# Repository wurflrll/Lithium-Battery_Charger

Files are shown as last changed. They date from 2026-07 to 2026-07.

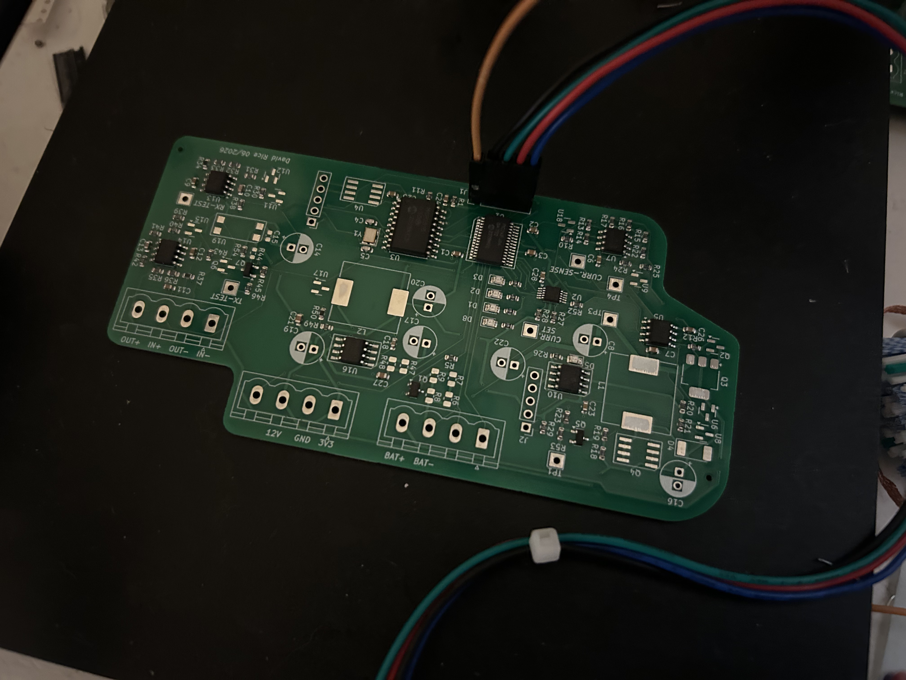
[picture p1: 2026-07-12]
images/oscilloscope/board_image_programmer.jpg

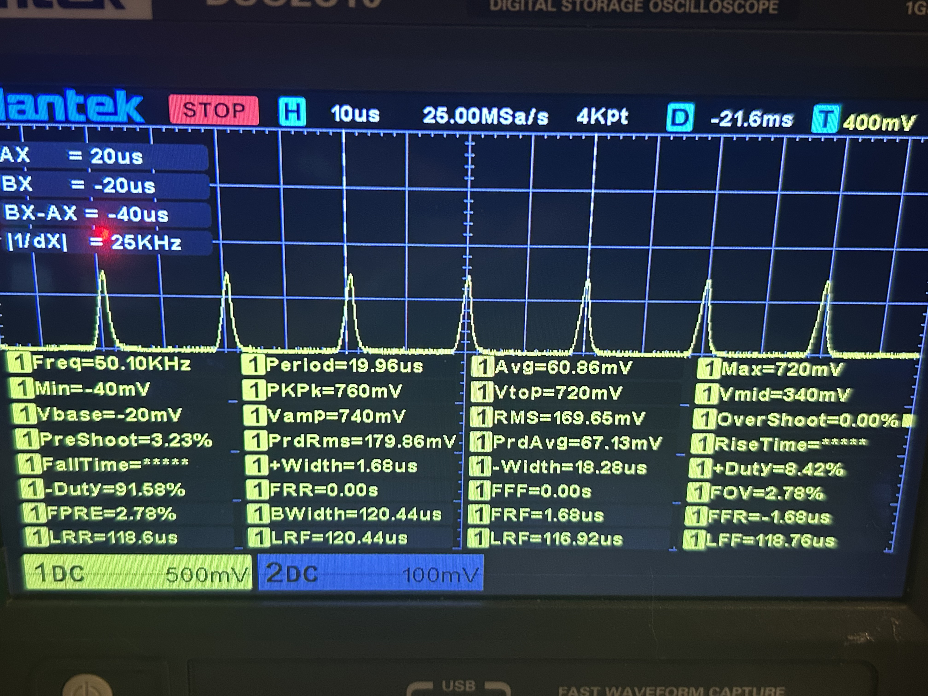
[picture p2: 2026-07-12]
images/oscilloscope/feedback_noise.jpg

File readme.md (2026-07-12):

# (Cascaded) Lithium-Ion Battery Charger 

The goals is a modular design for charging a lithium ion battery.  The board has two parts, the actual charging circuitry and the communication peripherals.

The communication peripherals includes an electrically isolated UART interface over a pulse transformer, an I2C interface to talk to the board's DAC module, and some general purpose inputs and outputs. 

Power Supply: 12V

V1 had a few issues, one was a layout error with the PIC microcontroller (I created the symbols itself in KiCad).  The other issue, much more interesting, is an issue with stability in the constant current controller.

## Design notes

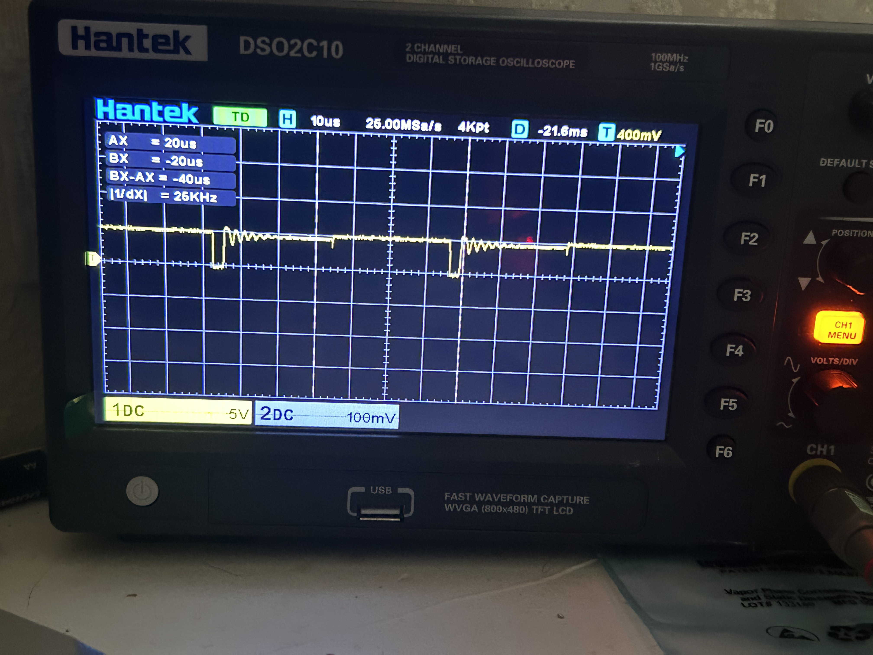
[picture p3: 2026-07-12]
images/oscilloscope/switching_inductive.jpg

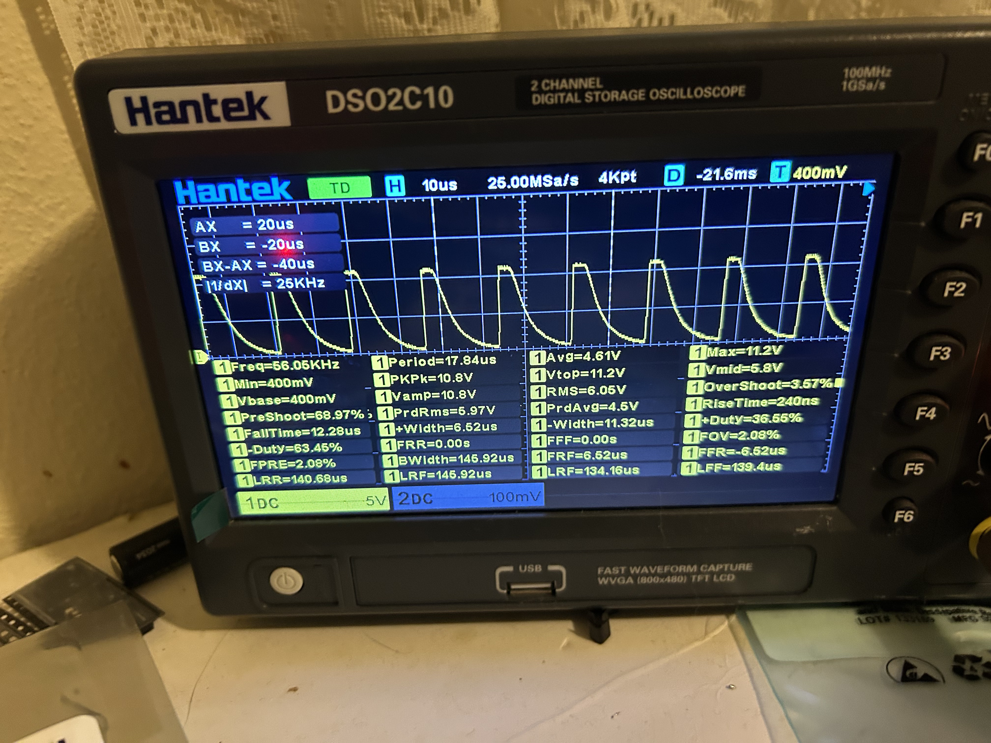
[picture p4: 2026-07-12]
images/oscilloscope/different_load_instability.jpg

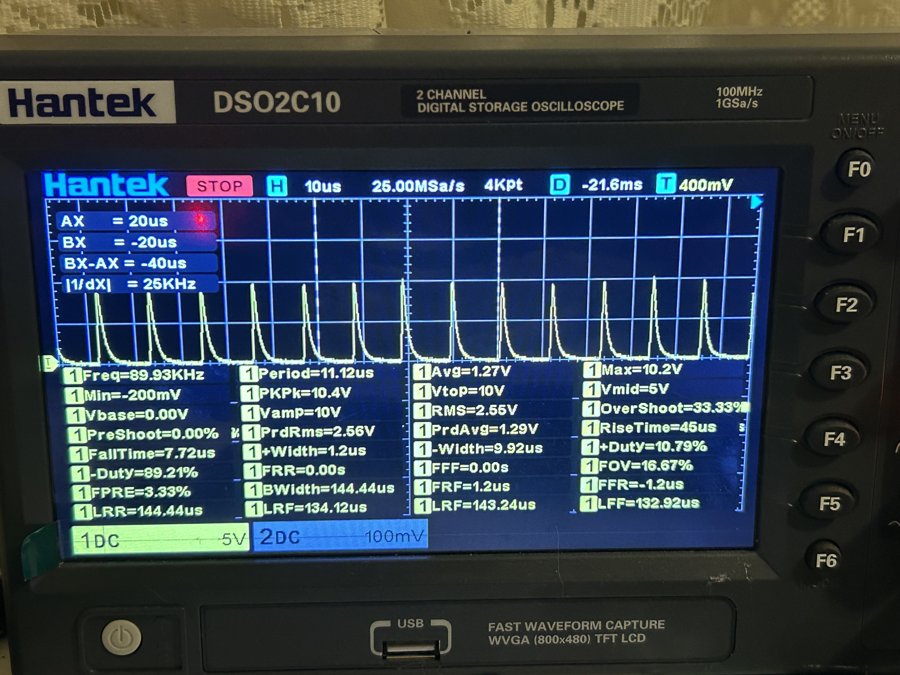
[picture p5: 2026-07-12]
images/oscilloscope/instability.jpg

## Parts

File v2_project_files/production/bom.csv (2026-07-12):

Designator | Footprint | Quantity | Value | LCSC Part #
C1, C11, C12, C2, C23, C24, C25, C26, C28, C6, C9 | 603 | 11 | 1uF | C29936
C10 | 603 | 1 | 22nF | C21122
C13 | 603 | 1 | 2.2nF | C107082
C14, C16, C17, C19, C20, C22, C8 | CP_Radial_D6.3mm_P2.50mm | 7 | 100uF
C18 | 603 | 1 | 1nF | C100040
C21, C27, C3, C7 | 603 | 4 | 10uF | C96446
C4, C5 | 603 | 2 | 30pF | C113797
D1, D2, D3, D5, D8 | 805 | 5 | LED | C19171391
D4 | D_MELF | 1 | SD560B
J1, J2, J4 | PinHeader_1x05_P2.54mm_Vertical | 3 | Conn_01x05_Pin
J3, J5, J6 | PhoenixContact_MSTBVA_2,5_4-G-5,08_1x04_P5.08mm_Vertical | 3 | Conn_01x04_Socket
L1, L2 | L_Sunlord_MWSA1205S-R36 | 2 | 220uH
Q1 | SOT-23 | 1 | AO3400A | C20917
Q2, Q6 | SOT-23 | 2 | Q_NPN_BEC | C81464
Q3 | SOT-223-3_TabPin2 | 1 | NSS60600MZ4 | C235754
Q4 | AOSP21313C | 1 | AOSP21313C
Q5, Q7 | SOT-23 | 2 | 2N7002 | C916396
R1, R11, R12, R13, R21, R27, R28, R29, R40, R41, R42 | 603 | 11 | 4.7K | C99782
R10, R23, R38, R43, R45, R46, R5, R52, R53 | 603 | 9 | 1K | C110776
R14, R15, R16, R17, R20, R22, R24, R25, R30, R32, R33, R35, R36 | 603 | 13 | 10K | C95204
R18, R19, R31, R54 | 603 | 4 | 100R | C122970
R2, R26, R3, R4, R51 | 603 | 5 | 133R | C5126161
R34, R37 | 603 | 2 | 2K | C844924
R39 | 603 | 1 | 510R | C113299
R47 | 805 | 1 | 0.511R
R49 | 603 | 1 | 5.6K | C2907046
R50 | 603 | 1 | 3.3K | C844928
R6, R7, R8, R9 | 805 | 4 | SHUNT?
TP1, TP2, TP3, TP4, TP5, TP8, TP9 | TestPoint_THTPad_2.5x2.5mm_Drill1.2mm | 7 | TestPoint
U1 | PIC24FJ64GA702 | 1 | ~ | C641965
U10 | PIC12F1501 | 1 | ~ | C76411
U11, U12, U15, U17, U18, U6, U8, U9 | ZLLS500TA | 8 | ~ | C154850
U13, U14, U5, U7 | SOIC-8_3.9x4.9mm_P1.27mm | 4 | NCS20072D | C89845
U16 | AZ34063U | 1 | ~ | C99659
U2 | MSOP-10_3x3mm_P0.5mm | 1 | MCP4728
U3 | SOIC-18W_7.5x11.6mm_P1.27mm | 1 | MCP2515-xSO | C153782
U4 | SN65HVD3082EDR | 1 | ~
Y1 | Crystal_SMD_Abracon_ABM8AIG-4Pin_3.2x2.5mm | 1 | Crystal_GND24 | C1986628

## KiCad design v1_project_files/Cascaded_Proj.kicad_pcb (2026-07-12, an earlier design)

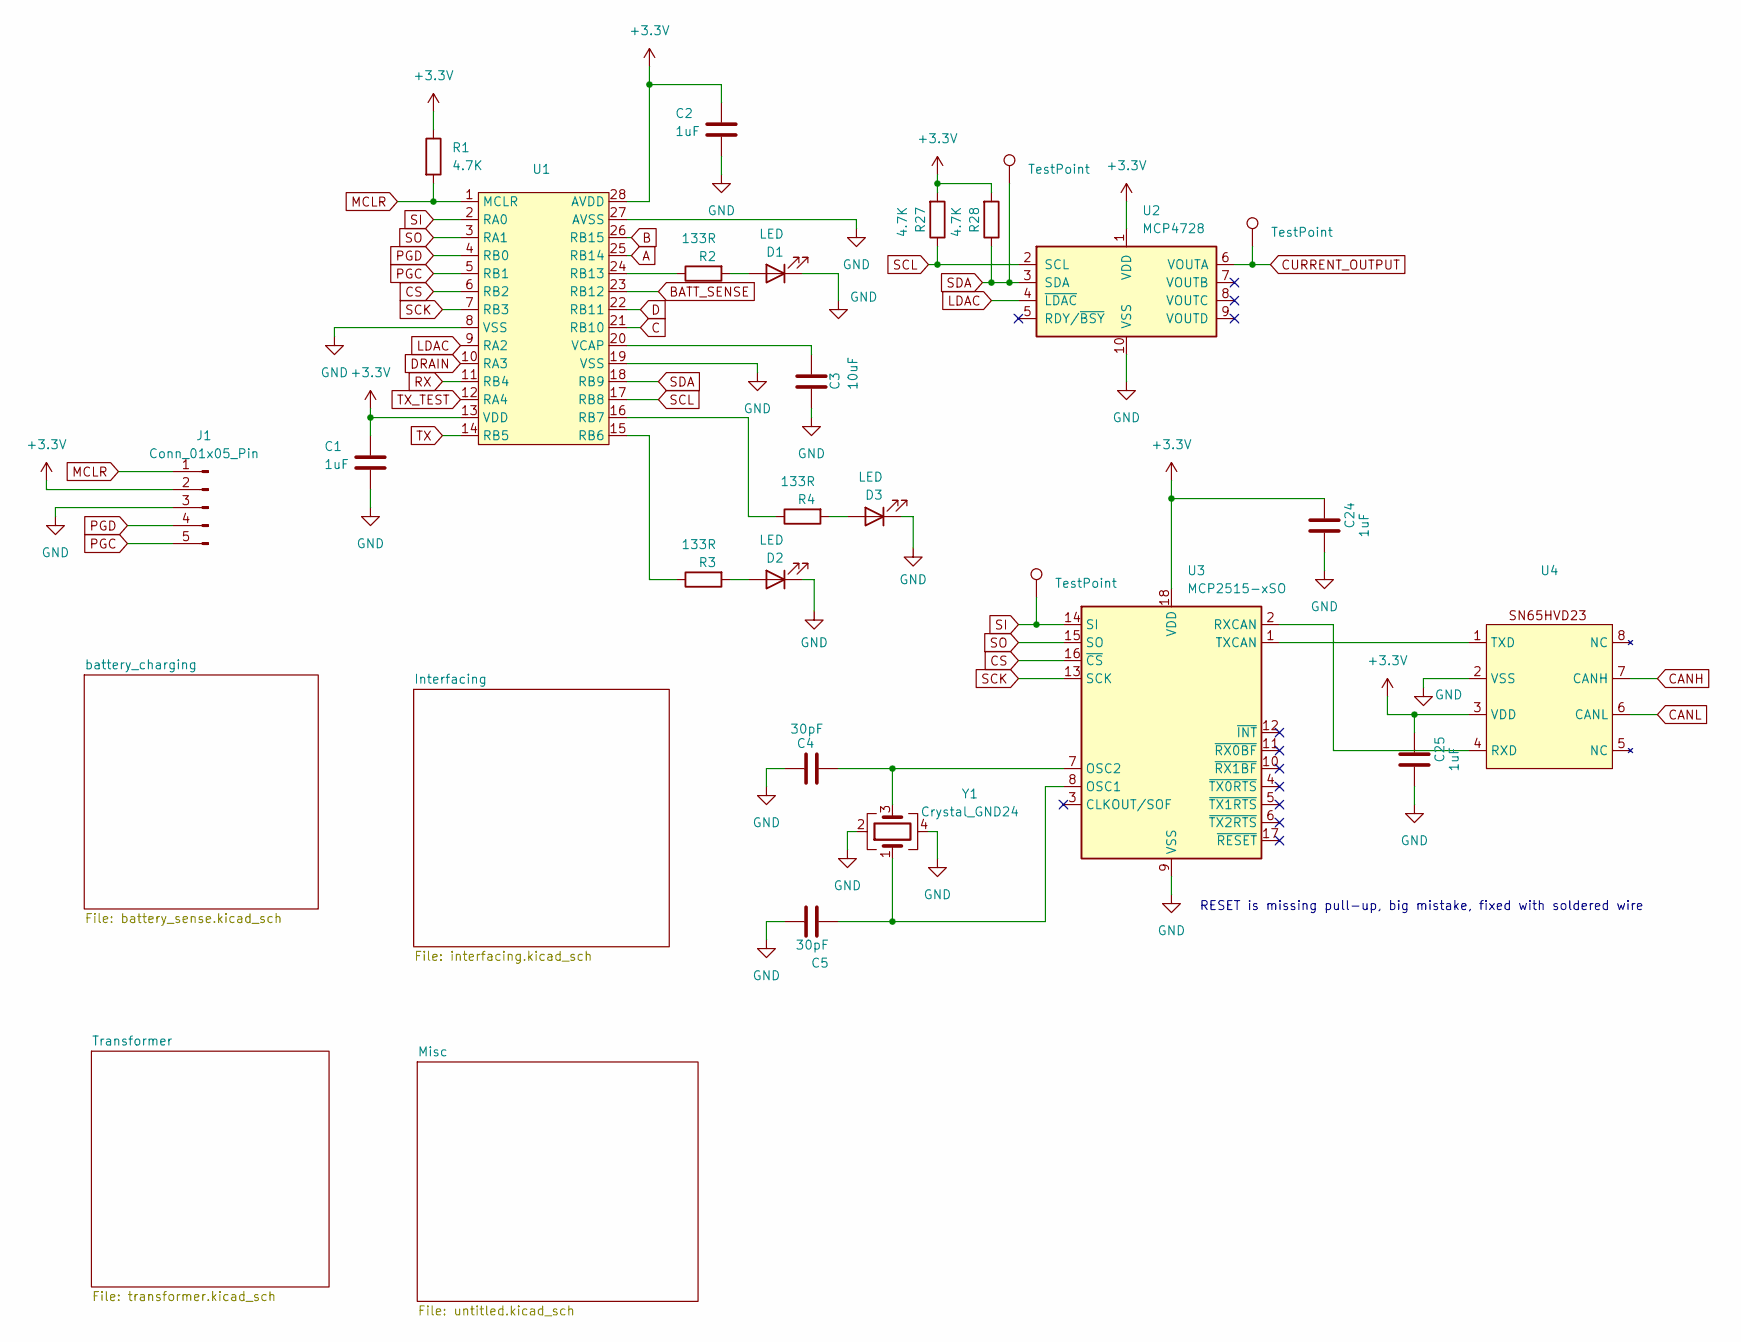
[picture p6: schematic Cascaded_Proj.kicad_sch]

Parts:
C1, C2, C24, C25: 1uF; C_0603_1608Metric
C3: 10uF; C_0603_1608Metric
C4, C5: 30pF; C_0603_1608Metric
D1, D2, D3: LED; LED_0805_2012Metric
J1: Conn_01x05_Pin; PinHeader_1x05_P2.54mm_Vertical
R1, R27, R28: 4.7K; R_0603_1608Metric
R2, R3, R4: 133R; R_0603_1608Metric
TP5, TP6, TP7: TestPoint; TestPoint_Plated_Hole_D2.0mm
U1: PIC24FJ64GA702
U2: MCP4728; MSOP-10_3x3mm_P0.5mm
U3: MCP2515-xSO; SOIC-18W_7.5x11.6mm_P1.27mm
U4: SN65HVD3082EDR
Y1: Crystal_GND24; Crystal_SMD_Abracon_ABM8AIG-4Pin_3.2x2.5mm

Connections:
+3.3V: C1.2, C2.2, C24.1, C25.1, J1.2, R1.1, R27.2, R28.2, U1.13 (VDD), U1.28 (AVDD), U2.1 (VDD), U3.18 (VDD), U4.3 (VDD); also elsewhere on the board
A: U1.25 (RB14); also elsewhere on the board
B: U1.26 (RB15); also elsewhere on the board
BATT_SENSE: U1.23 (RB12); also elsewhere on the board
C: U1.21 (RB10); also elsewhere on the board
CANH: U4.7 (CANH); also elsewhere on the board
CANL: U4.6 (CANL); also elsewhere on the board
CS: U1.6 (RB2), U3.16 (~CS)
CURRENT_OUTPUT: TP5.1, U2.6 (VOUTA); also elsewhere on the board
D: U1.22 (RB11); also elsewhere on the board
DRAIN: U1.10 (RA3); also elsewhere on the board
GND: C1.1, C2.1, C3.2, C4.1, C5.1, C24.2, C25.2, D1.1 (K), D2.1 (K), D3.1 (K), J1.3, U1.8 (VSS), U1.19 (VSS), U1.27 (AVSS), U2.10 (VSS), U3.9 (VSS), U4.2 (VSS), Y1.2, Y1.4; also elsewhere on the board
LDAC: U1.9 (RA2), U2.4 (~LDAC)
MCLR: J1.1, R1.2, U1.1 (MCLR)
unnamed: D1.2 (A), R2.2
unnamed: D2.2 (A), R3.2
unnamed: D3.2 (A), R4.2
unnamed: R3.1, U1.15 (RB6)
unnamed: R4.1, U1.16 (RB7)
unnamed: R2.1, U1.24 (RB13)
unnamed: C3.1, U1.20 (VCAP)
unnamed: C5.2, U3.8 (OSC1), Y1.1
unnamed: C4.2, U3.7 (OSC2), Y1.3
unnamed: U3.2 (RXCAN), U4.4 (RXD)
unnamed: U3.1 (TXCAN), U4.1 (TXD)
PGC: J1.5, U1.5 (RB1)
PGD: J1.4, U1.4 (RB0)
RX: U1.11 (RB4); also elsewhere on the board
SCK: U1.7 (RB3), U3.13 (SCK)
SCL: R27.1, U1.17 (RB8), U2.2 (SCL)
SDA: R28.1, TP6.1, U1.18 (RB9), U2.3 (SDA)
SI: TP7.1, U1.2 (RA0), U3.14 (SI)
SO: U1.3 (RA1), U3.15 (SO)
TX: U1.14 (RB5); also elsewhere on the board
TX_TEST: U1.12 (RA4); also elsewhere on the board

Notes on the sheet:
RESET is missing pull-up, big mistake, fixed with soldered wire

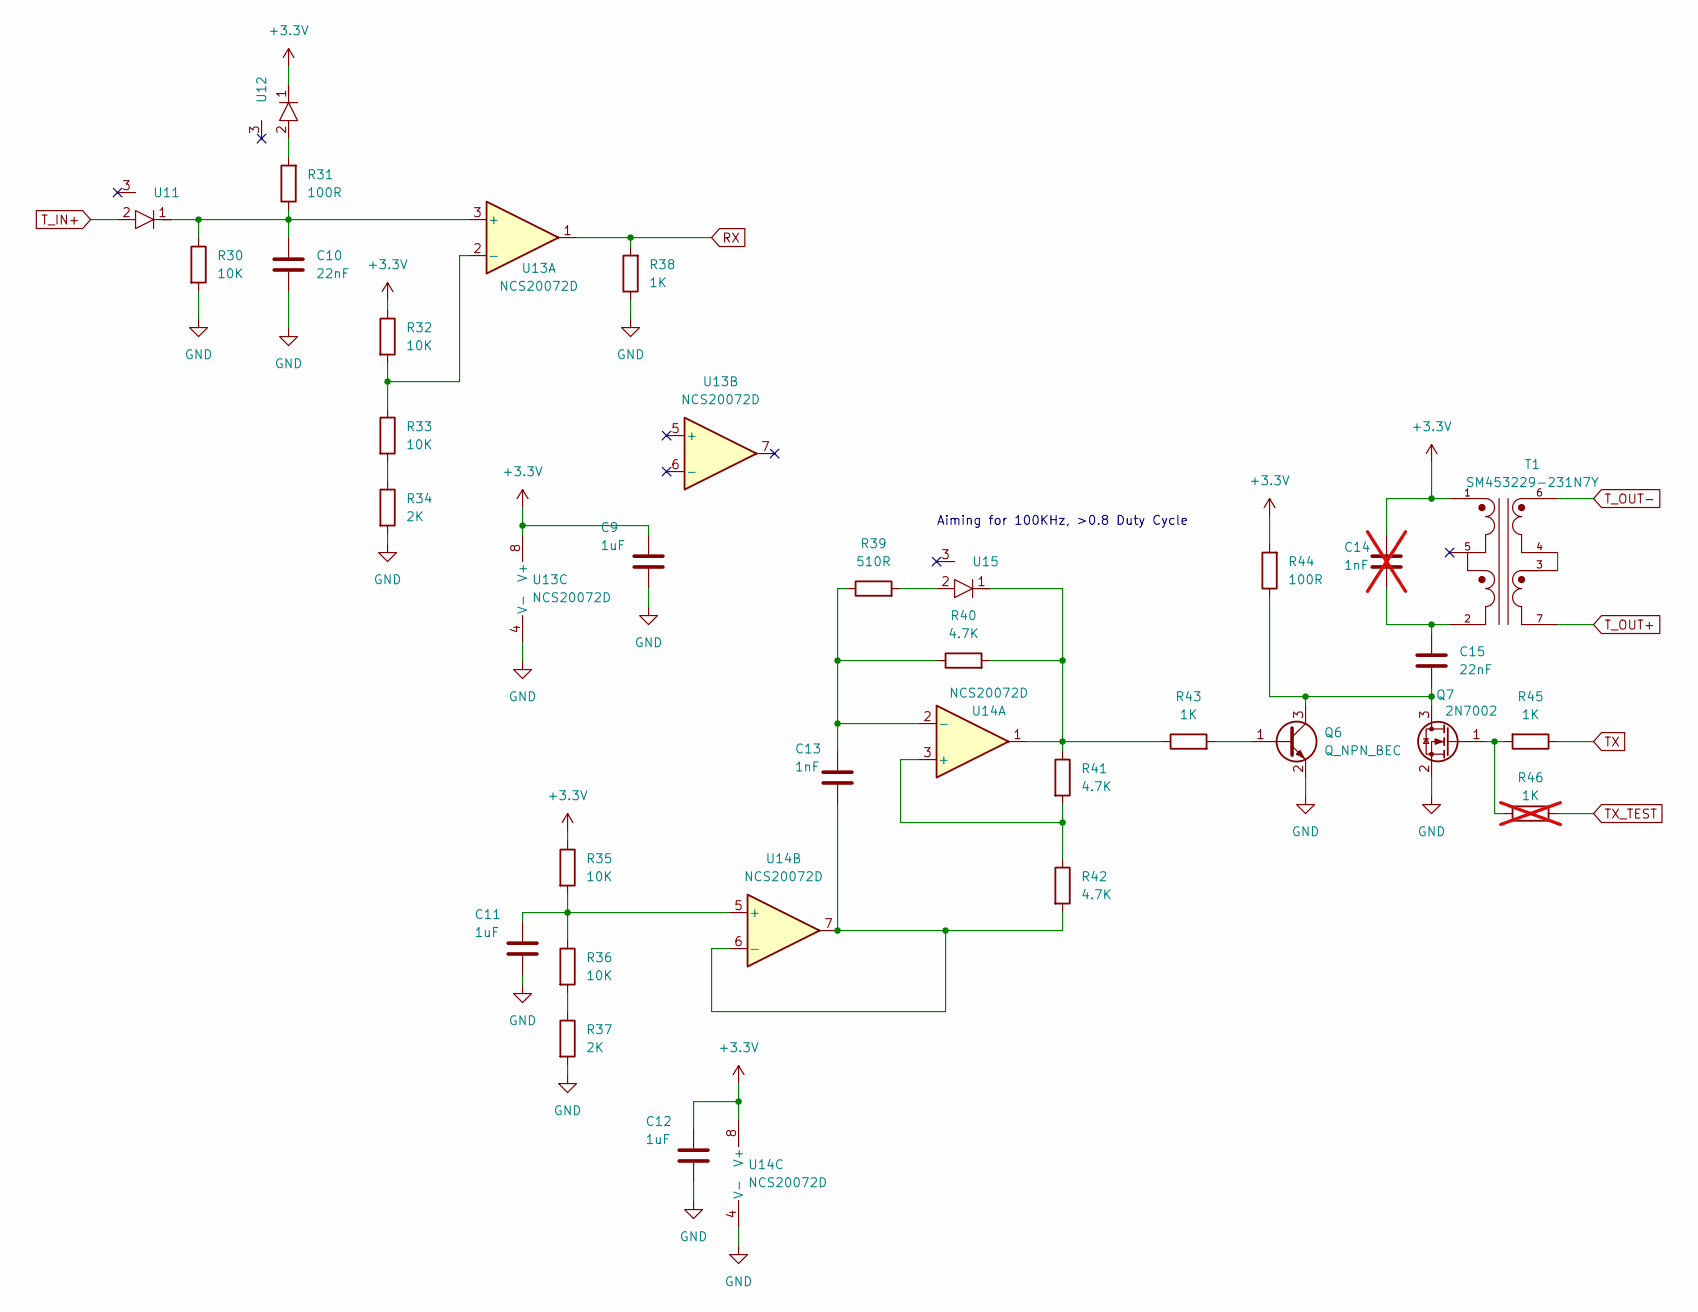
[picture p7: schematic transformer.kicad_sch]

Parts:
C9, C11, C12: 1uF; C_0603_1608Metric
C10, C15: 22nF; C_0603_1608Metric
C13: 1nF; C_0603_1608Metric
C14: 1nF; C_0603_1608Metric; not fitted
Q6: Q_NPN_BEC; SOT-23
Q7: 2N7002; SOT-23
R30, R32, R33, R35, R36: 10K; R_0603_1608Metric
R31, R44: 100R; R_0603_1608Metric
R34, R37: 2K; R_0603_1608Metric
R38, R43, R45: 1K; R_0603_1608Metric
R39: 510R; R_0603_1608Metric
R40, R41, R42: 4.7K; R_0603_1608Metric
R46: 1K; R_0603_1608Metric; not fitted
T1: SM453229-231N7Y
U11, U12, U15: ZLLS500TA
U13, U14: NCS20072D; SOIC-8_3.9x4.9mm_P1.27mm

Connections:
+3.3V: C9.1, C12.1, C14.1, R32.1, R35.1, R44.2, T1.1, U12.1, U13.8 (V+), U14.8 (V+); also elsewhere on the board
GND: C9.2, C10.1, C11.2, C12.2, Q6.2 (E), Q7.2 (S), R30.2, R34.2, R37.2, R38.1, U13.4 (V-), U14.4 (V-); also elsewhere on the board
unnamed: C14.2, C15.1, T1.2
unnamed: Q6.1 (B), R43.2
unnamed: C15.2, Q6.3 (C), Q7.3 (D), R44.1
unnamed: Q7.1 (G), R45.2, R46.1
unnamed: R31.2, U12.2
unnamed: R33.2, R34.1
unnamed: R36.2, R37.1
unnamed: R39.2, U15.2
unnamed: R40.2, R41.1, R43.1, U14.1, U15.1
unnamed: T1.3, T1.4
unnamed: C10.2, R30.1, R31.1, U11.1, U13.3 (+)
unnamed: R32.2, R33.1, U13.2 (-)
unnamed: R41.2, R42.1, U14.3 (+)
unnamed: C13.1, R39.1, R40.1, U14.2 (-)
unnamed: C11.1, R35.2, R36.1, U14.5 (+)
unnamed: C13.2, R42.2, U14.6 (-), U14.7
RX: R38.2, U13.1; also elsewhere on the board
TX: R45.1; also elsewhere on the board
TX_TEST: R46.2; also elsewhere on the board
T_IN+: U11.2; also elsewhere on the board
T_OUT+: T1.7; also elsewhere on the board
T_OUT-: T1.6; also elsewhere on the board

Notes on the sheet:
Aiming for 100KHz, >0.8 Duty Cycle

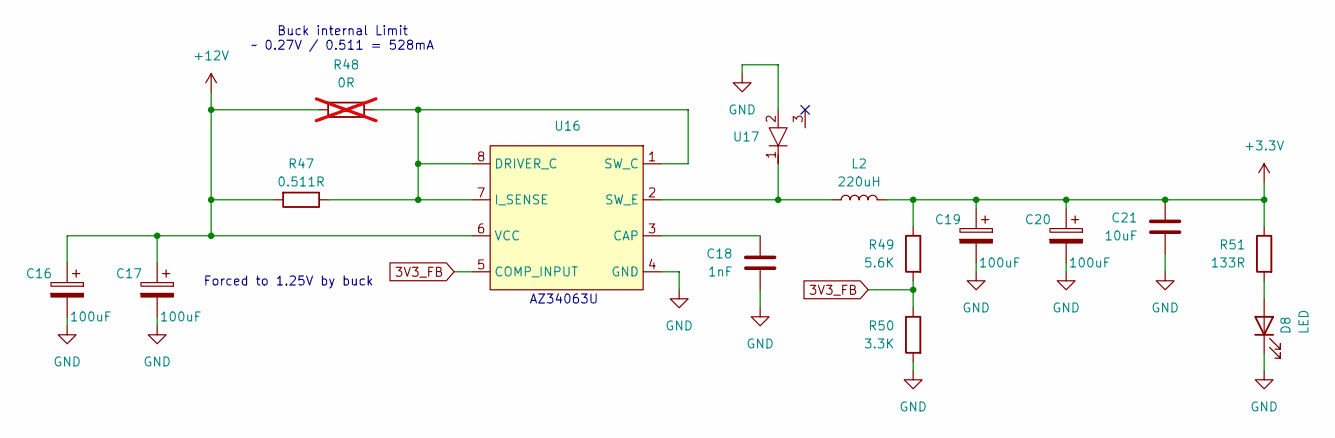
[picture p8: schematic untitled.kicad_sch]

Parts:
C16, C17, C19, C20: 100uF; CP_Radial_D6.3mm_P2.50mm
C18: 1nF; C_0603_1608Metric
C21: 10uF; C_0603_1608Metric
D8: LED; LED_0805_2012Metric
L2: 220uH; L_Sunlord_MWSA1205S-R36
R47: 0.511R; R_0805_2012Metric
R48: 0R; R_0805_2012Metric; not fitted
R49: 5.6K; R_0603_1608Metric
R50: 3.3K; R_0603_1608Metric
R51: 133R; R_0603_1608Metric
U16: AZ34063U
U17: ZLLS500TA

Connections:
3V3_FB: R49.2, R50.1, U16.5 (COMP_INPUT)
+3.3V: C19.1, C20.1, C21.1, L2.1, R49.1, R51.1; also elsewhere on the board
+12V: C16.1, C17.1, R47.2, R48.1, U16.6 (VCC); also elsewhere on the board
GND: C16.2, C17.2, C18.2, C19.2, C20.2, C21.2, D8.1 (K), R50.2, U16.4 (GND), U17.2; also elsewhere on the board
unnamed: D8.2 (A), R51.2
unnamed: C18.1, U16.3 (CAP)
unnamed: R47.1, R48.2, U16.1 (SW_C), U16.7 (I_SENSE), U16.8 (DRIVER_C)
unnamed: L2.2, U16.2 (SW_E), U17.1

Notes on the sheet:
AZ34063U
Forced to 1.25V by buck
Buck internal Limit ~ 0.27V / 0.511 = 528mA

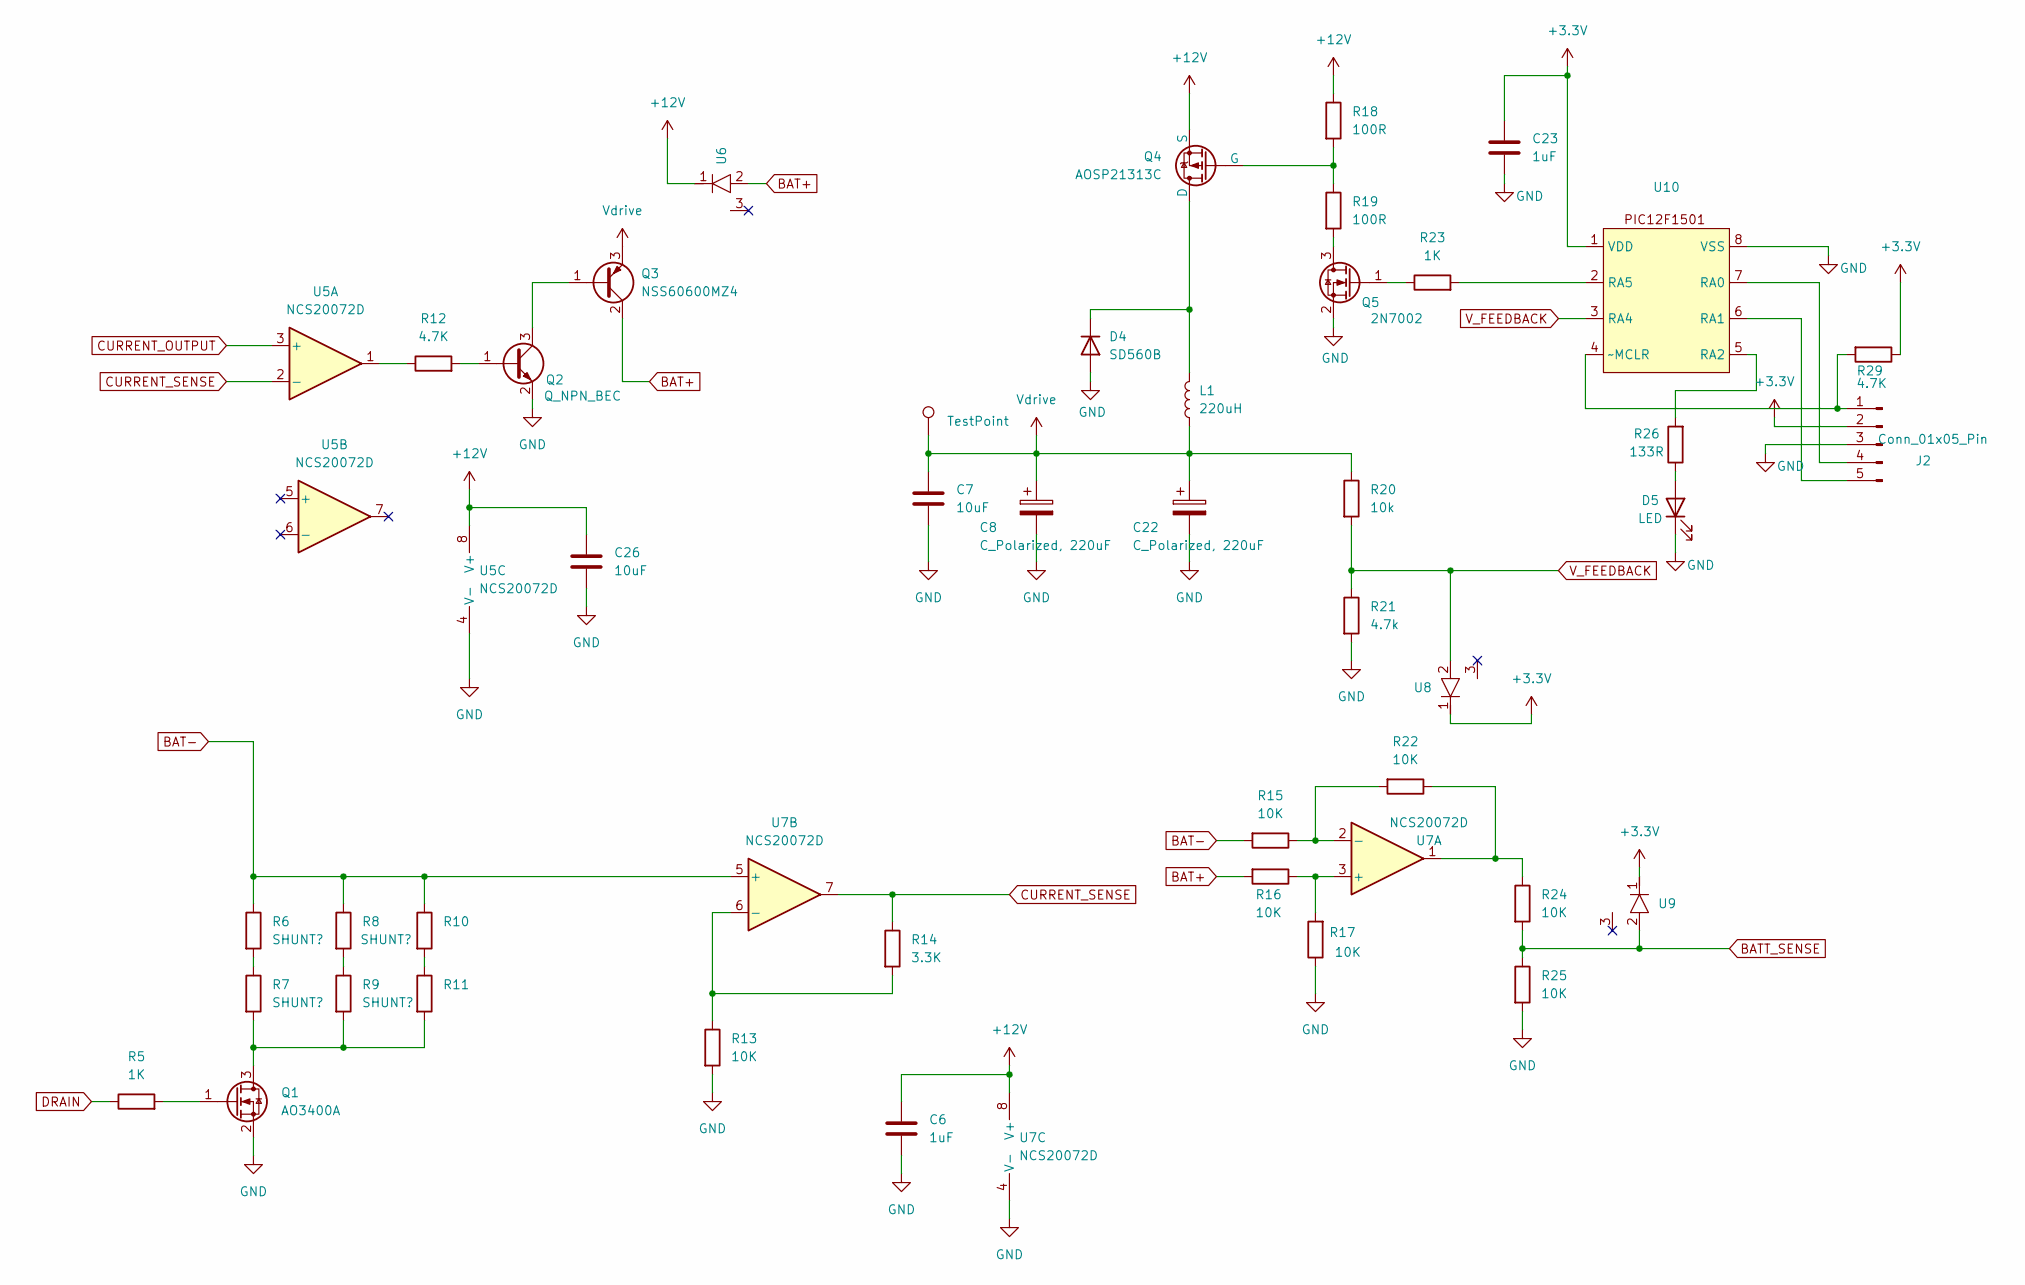
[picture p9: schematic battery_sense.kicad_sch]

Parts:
C6, C23: 1uF; C_0603_1608Metric
C7, C26: 10uF; C_0603_1608Metric
C8, C22: C_Polarized, 220uF; CP_Radial_D18.0mm_P7.50mm
D4: SD560B; D_MELF
D5: LED; LED_0805_2012Metric
J2: Conn_01x05_Pin; PinHeader_1x05_P2.54mm_Vertical
L1: 220uH; 2300HT-221-H-RC
Q1: AO3400A; SOT-23
Q2: Q_NPN_BEC; SOT-23
Q3: NSS60600MZ4; SOT-223-3_TabPin2
Q4: AOSP21313C
Q5: 2N7002; SOT-23
R5, R23: 1K; R_0603_1608Metric
R6, R7, R8, R9, R10, R11: SHUNT?; R_0805_2012Metric
R12, R29: 4.7K; R_0603_1608Metric
R13, R15, R16, R17, R22, R24, R25: 10K; R_0603_1608Metric
R14: 3.3K; R_0603_1608Metric
R18, R19: 100R; R_0603_1608Metric
R20: 10k; R_0603_1608Metric
R21: 4.7k; R_0603_1608Metric
R26: 133R; R_0603_1608Metric
TP3: TestPoint; TestPoint_Plated_Hole_D2.0mm
U5, U7: NCS20072D; SOIC-8_3.9x4.9mm_P1.27mm
U6, U8, U9: ZLLS500TA
U10: PIC12F1501

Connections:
+3.3V: C23.1, J2.2, R29.1, U8.1, U9.1, U10.1 (VDD); also elsewhere on the board
+12V: C6.1, C26.1, Q4.3 (S), R18.1, U5.8 (V+), U6.1, U7.8 (V+); also elsewhere on the board
BAT+: Q3.2 (C), R16.2, U6.2; also elsewhere on the board
BAT-: R6.1, R8.1, R10.1, R15.2, U7.5 (+); also elsewhere on the board
BATT_SENSE: R24.2, R25.1, U9.2; also elsewhere on the board
CURRENT_OUTPUT: U5.3 (+); also elsewhere on the board
CURRENT_SENSE: R14.1, U5.2 (-), U7.7
DRAIN: R5.1; also elsewhere on the board
GND: C6.2, C7.2, C8.2, C22.2, C23.2, C26.2, D4.2 (A), D5.1 (K), J2.3, Q1.2 (S), Q2.2 (E), Q5.2 (S), R13.2, R17.1, R21.2, R25.2, U5.4 (V-), U7.4 (V-), U10.8 (VSS); also elsewhere on the board
unnamed: D4.1 (K), L1.2, Q4.1 (D)
unnamed: D5.2 (A), R26.1
unnamed: J2.1, R29.2, U10.4 (~MCLR)
unnamed: J2.4, U10.7 (RA0)
unnamed: J2.5, U10.6 (RA1)
unnamed: Q1.3 (D), R7.2, R9.2, R11.2
unnamed: Q1.1 (G), R5.2
unnamed: Q2.1 (B), R12.2
unnamed: Q2.3 (C), Q3.1 (B)
unnamed: Q4.2 (G), R18.2, R19.1
unnamed: Q5.3 (D), R19.2
unnamed: Q5.1 (G), R23.1
unnamed: R6.2, R7.1
unnamed: R8.2, R9.1
unnamed: R10.2, R11.1
unnamed: R12.1, U5.1
unnamed: R22.1, R24.1, U7.1
unnamed: R16.1, R17.2, U7.3 (+)
unnamed: R15.1, R22.2, U7.2 (-)
unnamed: R13.1, R14.2, U7.6 (-)
unnamed: R26.2, U10.5 (RA2)
unnamed: R23.2, U10.2 (RA5)
V_FEEDBACK: R20.2, R21.1, U8.2, U10.3 (RA4)
Vdrive: C7.1, C8.1, C22.1, L1.1, Q3.3 (E), R20.1, TP3.1

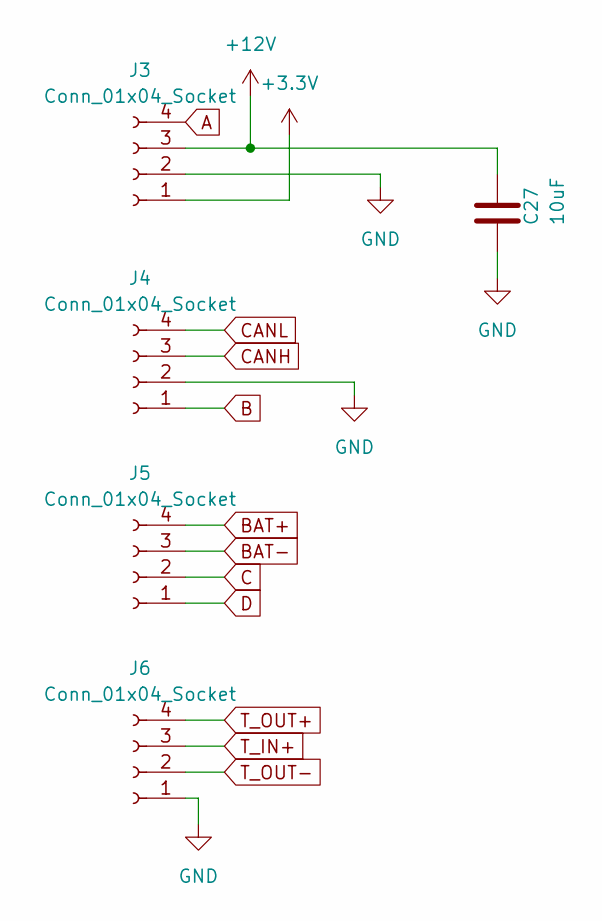
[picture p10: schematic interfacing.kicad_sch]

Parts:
C27: 10uF; C_0603_1608Metric
J3, J4, J5, J6: Conn_01x04_Socket; PhoenixContact_MSTBVA_2,5_4-G-5,08_1x04_P5.08mm_Vertical

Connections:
+3.3V: J3.1; also elsewhere on the board
+12V: C27.1, J3.3; also elsewhere on the board
A: J3.4; also elsewhere on the board
B: J4.1; also elsewhere on the board
BAT+: J5.4; also elsewhere on the board
BAT-: J5.3; also elsewhere on the board
C: J5.2; also elsewhere on the board
CANH: J4.3; also elsewhere on the board
CANL: J4.4; also elsewhere on the board
D: J5.1; also elsewhere on the board
GND: C27.2, J3.2, J4.2, J6.1; also elsewhere on the board
T_IN+: J6.3; also elsewhere on the board
T_OUT+: J6.4; also elsewhere on the board
T_OUT-: J6.2; also elsewhere on the board

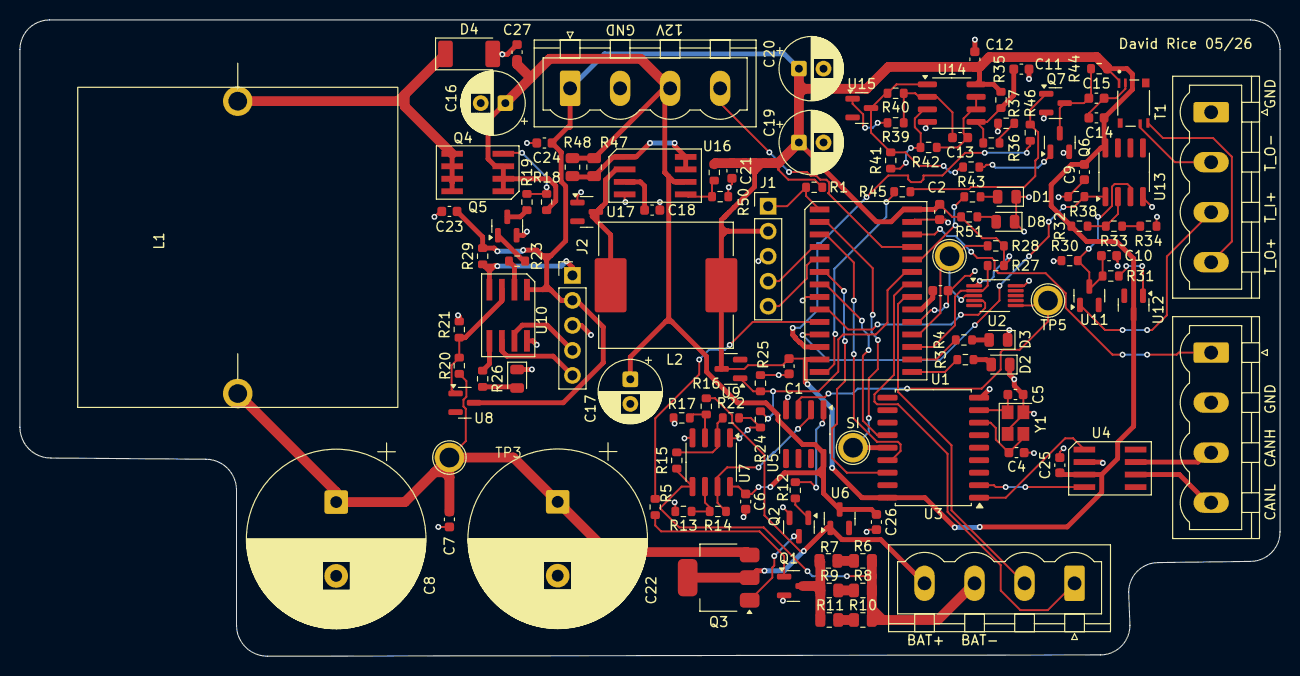
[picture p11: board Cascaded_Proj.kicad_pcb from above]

Board: 2 copper layers, 128.0 x 64.6 mm, 122 parts (0 on the bottom side), 87 nets.

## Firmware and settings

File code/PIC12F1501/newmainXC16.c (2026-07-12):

#include <xc.h>
#include <stdint.h>

#define _XTAL_FREQ 16000000

// CONFIG1
#pragma config FOSC = INTOSC
#pragma config WDTE = OFF
#pragma config PWRTE = OFF
#pragma config MCLRE = OFF
#pragma config CP = OFF
#pragma config BOREN = ON
#pragma config CLKOUTEN = OFF

// CONFIG2
#pragma config WRT = OFF
#pragma config STVREN = ON
#pragma config LVP = OFF

void OSC_Init(void)
{
    // 16 MHz HFINTOSC
    OSCCON = 0b01111010;
}

void GPIO_Init(void)
{
    // RA4 = analog
    ANSELA = 0b00010000;

    TRISAbits.TRISA4 = 1;
    TRISAbits.TRISA2 = 0;
    TRISAbits.TRISA5 = 0;

    LATA = 0;
}

void ADC_Init(void)
{
    // AN3 = RA4
    ADCON0bits.CHS = 0b0011;
    ADCON1bits.ADFM = 1;      // Right justified
    ADCON1bits.ADCS = 0b110;  // Fosc/64
    ADCON0bits.ADON = 1;
}

uint16_t ADC_Read(void)
{
    __delay_us(10);

    ADCON0bits.GO = 1;
    while (ADCON0bits.GO);

    return ((uint16_t)ADRESH << 8) | ADRESL;
}

void PWM4_Init(void)
{
    //
    // Timer2
    //
    PR2 = 255;

    T2CONbits.T2CKPS = 0;     // 1:1
    T2CONbits.TMR2ON = 1;

    //
    // Initial duty = 0
    //
    PWM4DCH = 0;
    PWM4DCL = 0;

    //
    // Enable PWM4 output
    //
    PWM4CONbits.PWM4OE = 1;
    PWM4CONbits.PWM4EN = 1;
}

void PWM4_SetDuty(uint16_t duty)
{
    if (duty > 1023)
        duty = 1023;

    PWM4DCH = duty >> 2;
    PWM4DCL = (duty & 0x03) << 6;
}


// 
uint16_t increment = 48;
uint16_t duty_value = 1023 >> 1;

void PeformFeedback(uint16_t set_voltage) { 
    uint16_t measured = ADC_Read();
    uint16_t increment = 48;
    if (measured > set_voltage) { 
        if (increment + duty_value < duty_value) { 
            duty_value = 1023;
        }
        else {
            duty_value += increment;
        }
    }
    else {
        if (duty_value - increment > duty_value) {
            duty_value = 0;
        }
        else {
            duty_value -= increment;
        }
    }
    PWM4_SetDuty(duty_value);
}




int main(void)
{
    uint16_t adc;
    uint16_t count = 0;

    OSC_Init();
    GPIO_Init();
    ADC_Init();
    PWM4_Init();

    
    PWM4_SetDuty(511);

    while (1)
    {
        // 0x03FF = 10.321
        // so 0.01008 nominal V / bit
        PeformFeedback(500);
//        adc = ADC_Read();
//
//        if (++count >= 45000)
//        {
//            LATAbits.LATA2 = 1;
//        }
//        else {
//            LATAbits.LATA2 = 0;
//        }
        
    }
}

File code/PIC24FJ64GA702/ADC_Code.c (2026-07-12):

#define FCY 4000000UL     // Instruction clock = 4 MHz
#pragma config JTAGEN = OFF

#include <xc.h>
#include <libpic30.h>     // for __delay_ms()

void I2C_Start() {
   I2C1CONLbits.SEN = 1;         // Start condition
   while(I2C1CONLbits.SEN);
}

void I2C_Stop() {
   I2C1CONLbits.PEN = 1;         // Stop condition
   while(I2C1CONLbits.PEN);
}

int I2C_ERROR() {
   LATBbits.LATB13 = 1;
   return 1;
}


uint8_t first_byte;
uint8_t second_byte;

// only takes 12 bit number
int WriteDACvalue(uint16_t value) {  
    first_byte = 0x0F & (value >> 8);
    second_byte = value & (0xFF);    
    
    
    _MI2C1IF = 0;
    
    while(!_MI2C1IF); _MI2C1IF = 0;
    // 1st and 4th bits are VREF and GAIN, set to 0
    // VREF = 0 (VDD)
    // DAC0 = 0)
    // DAC1 = 0
    // GAIN = 0 (1x Gain)
    first_byte = 0b00000000 | first_byte;
    
    I2C_Start();
                    
    // addressing
    I2C1TRN = 0b11000000;
    //while(I2C1STATbits.TRSTAT);
    //while(!_MI2C1IF); _MI2C1IF = 0;
    while(I2C1STATbits.TBF);
    
    if (I2C1STATbits.ACKSTAT) { 
        return I2C_ERROR();
    }
    
    // send 01011000 -> will automatically set output
    // bits for single-write command
    I2C1TRN = 0b01011000;
    //while(I2C1STATbits.TRSTAT);
    //while(!_MI2C1IF); _MI2C1IF = 0;
    while(I2C1STATbits.TBF);

    if (I2C1STATbits.ACKSTAT) { 
        return I2C_ERROR();
    }
       
    
    // send first byte
    I2C1TRN = first_byte;
    //while(I2C1STATbits.TRSTAT);
    //while(!_MI2C1IF); _MI2C1IF = 0;
    while(I2C1STATbits.TBF);
  
    if (I2C1STATbits.ACKSTAT) { 
        return I2C_ERROR();
    }
    
    I2C1TRN = second_byte;
    //while(I2C1STATbits.TRSTAT);
    //while(!_MI2C1IF); _MI2C1IF = 0;
    while(I2C1STATbits.TBF);
    
    if (I2C1STATbits.ACKSTAT) { 
        return I2C_ERROR();
    }    
    
    I2C_Stop();
    return 0;
}

int WriteGain() {
    
    _MI2C1IF = 0;

        
   I2C_Start();
   
   I2C1TRN = 0b11000000;
   //while(!_MI2C1IF); _MI2C1IF = 0;
    while(I2C1STATbits.TBF);
       
   if (I2C1STATbits.ACKSTAT) { 
       return I2C_ERROR();
   }
   
   I2C1TRN = 0b11000000;
   //while(!_MI2C1IF); _MI2C1IF = 0;
    while(I2C1STATbits.TBF);
       
   if (I2C1STATbits.ACKSTAT) { 
       return I2C_ERROR();
   }
   
   I2C_Stop();
   return 0;
}


int WriteVREF() {
   I2C_Start();

   
   _MI2C1IF = 0;

   I2C1TRN = 0b11000000;
   //while(!_MI2C1IF); _MI2C1IF = 0;
    while(I2C1STATbits.TBF);
       
   if (I2C1STATbits.ACKSTAT) { 
       return I2C_ERROR();
   }
   I2C1TRN = 0b10000000;
   //while(!_MI2C1IF); _MI2C1IF = 0;
    while(I2C1STATbits.TBF);
       
   if (I2C1STATbits.ACKSTAT) { 
       return I2C_ERROR();
   }
   I2C_Stop();
   return 0;
}


int FastWriteDAC(uint16_t value) {
    
    
    _MI2C1IF = 0;

        
    first_byte = 0x0F & (value >> 8);
    second_byte = value & (0xFF);    
    
    // for Fast write command
    // first two bits are 0
    // next two bits are channel select
    
    first_byte = 0b00000000 | first_byte;
    
    I2C_Start();
                    
    // addressing
    I2C1TRN = 0b11000000;
    //while(!_MI2C1IF); _MI2C1IF = 0;
    while(I2C1STATbits.TBF);
        
    if (I2C1STATbits.ACKSTAT) { 
        return I2C_ERROR();
    }
       
    
    // send first byte
    I2C1TRN = first_byte;
    //while(!_MI2C1IF); _MI2C1IF = 0;
    while(I2C1STATbits.TBF);
        
    if (I2C1STATbits.ACKSTAT) { 
        return I2C_ERROR();
    }
    
    I2C1TRN = second_byte;
    //while(!_MI2C1IF); _MI2C1IF = 0;
    while(I2C1STATbits.TBF);
        
    if (I2C1STATbits.ACKSTAT) { 
        return I2C_ERROR();
    }    
    
    I2C_Stop();
    return 0;
}
   

int GeneralWrite(uint8_t data) {
    
   I2C1TRN = data;
   //while(!_MI2C1IF); _MI2C1IF = 0;
    while(I2C1STATbits.TBF);
   
   if (I2C1STATbits.ACKSTAT) { 
       return I2C_ERROR();
   }    
   return 0;
}


int main(void) {
   
   // SDA is RB9
   // SCL is RB8
   // LDAC is RA2, but should be unused
   
   // set up error LED
   
#ifdef ANSB
   ANSBbits.ANSB13 = 0;      // Disable analog function if present
#endif
   TRISBbits.TRISB13 = 0;    // RB13 = output
   
   LATBbits.LATB13 = 0; // ERROR LED    
   
   ODCBbits.ODCB8 = 1; // Enable Open-Drain on SCL1 (RB8)
   ODCBbits.ODCB9 = 1; // Enable Open-Drain on SDA1 (RB9
   // I2C Config: 
   
   PMD1bits.I2C1MD = 0; // disable before setting
   
   // 1. Completely clear control registers first to reset the I2C state machine
   I2C1CONL = 0;
   I2C1CONH = 0;

   ANSELBbits.ANSB9 = 0; // Basic initialization for SDA/SCL pins
   TRISBbits.TRISB8 = 0;
   TRISBbits.TRISB9 = 0;

   // 3. Set Baud Rate 
   I2C1BRG = 18;

   // 4. Enable the I2C Module LAST
   I2C1CONLbits.I2CEN = 1;    
   
   TRISAbits.TRISA2 = 0; // Initialize Error LED
   LATAbits.LATA2 = 0;


   if(I2C1CONLbits.I2CEN == 0) {
       while(1);
   }
   // CALL General Reset
   I2C_Start();

   GeneralWrite(0b00000000);
    
   GeneralWrite(0b00000110);
    
   I2C_Stop();
   
   __delay_ms(20);
    
    // CALL General Wakeup
    
    I2C_Start();

    GeneralWrite(0b00000000);
    
    GeneralWrite(0b00001001);
  
    I2C_Stop();   
    __delay_ms(20);
    
    WriteVREF();
    __delay_ms(20);

    
    WriteGain();
    __delay_ms(20);

    
    
    while(1) {
        
        for (uint16_t i = 0; i < 4096; ++i) {
            WriteDACvalue(i);
            __delay_ms(5);
        }
    }            
    return 0;
}

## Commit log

2026-05-28 update pcb layout
    [Cascaded_Proj.kicad_pcb, Cascaded_Proj.kicad_sch, battery_sense.kicad_sch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]
2026-07-12 added images of instability
    [Cascaded_Proj-B_Cu.gbl, Cascaded_Proj-B_Mask.gbs, Cascaded_Proj-B_Paste.gbp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]
